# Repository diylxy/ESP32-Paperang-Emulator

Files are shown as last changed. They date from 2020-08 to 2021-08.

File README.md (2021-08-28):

# ESP32 Paperang Emulator

#### 用ESP32 DIY 热敏打印机，模拟Paperang/喵喵机通信协议，可以通过蓝牙连接手机，接收、打印Paperang APP/喵喵机APP/作业帮APP发送的打印数据

## 提示  2021-8-28
#### 这个版本过于不完善，我也在尝试制作2.0版，但是因为学业原因可能需要*很久*，所以推荐两个优秀的二次开发项目，如果资金充足可以考虑：  
[Mao喵喵机热敏打印机--樱猫](https://www.oshwhub.com/SakuraNeko/mao-re-min-da-yin-ji)  
[喵喵机-热敏打印机-改--freedom789](https://www.oshwhub.com/freedom789/print-fpc1)  
因为我比较菜，又要考虑兼容性问题，所以就没有画fpc，这个项目就当是模板吧。这里给各位二次开发者一些建议：  
电池最好更换为2节串联，不要用原版升压芯片，或者电池加超级电容，不然带不动；  
电机驱动可以考虑a4988驱动芯片，不要采用恒压驱动的方式，那样的话电机会非常热；  
原版电路mos管驱动可能有问题，但是能用，这个保护电路不可以省略，不然上电esp32某些引脚默认会上拉或下拉，stb就会激活，烧出一条黑线；  
esp32不需要wrover，根据我的计算60k缓冲区足够打印1m长，把ps_malloc改成malloc就行。  
欢迎大家二次开发并开源，只要注明一下原作者就可以。  
下面是正文  

---
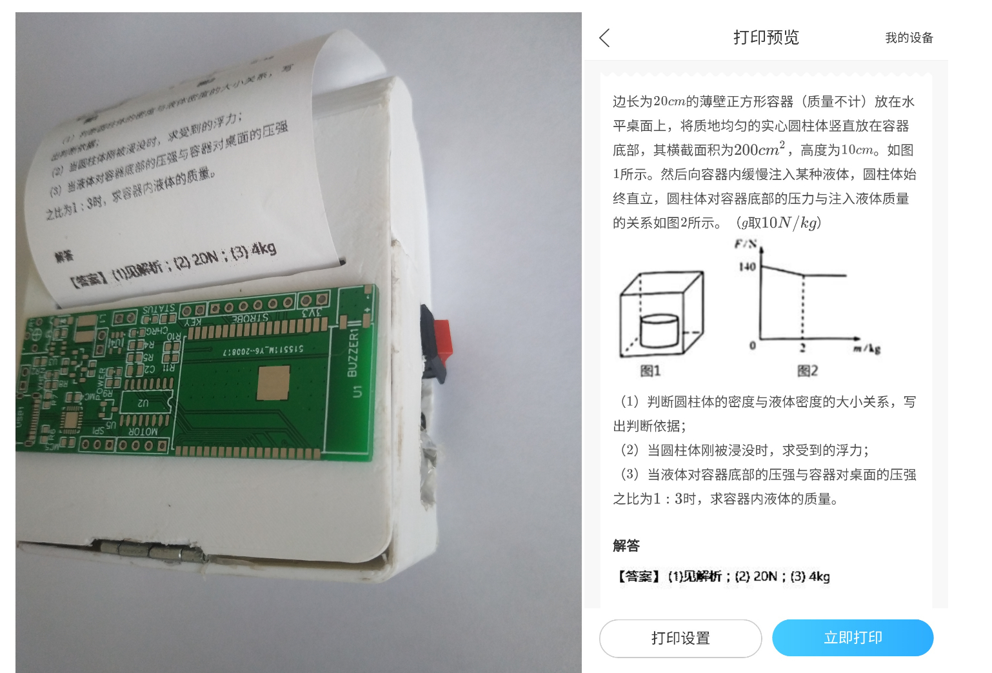
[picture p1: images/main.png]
封面


[Bilibili视频链接](https://www.bilibili.com/video/BV1v54y127xZ )

-----

** 3D模型可能不适合你的打印头,如果打印头尺寸与3D模型相差太大建议重新设计3D模型 **

## 注意事项/调试过程

** 注意：以下内容必须认真阅读，否则可能会出现各种问题，甚至烧坏打印头 **

PCB上的SDA接打印头的SI

已经确认STB5 STB6不能作为输出引脚，ADC和KEY没用到，可以按照视频说明接到那两个引脚上

如果下载程序时不能自动复位可以在ESP32的EN脚对地并联一个20uf以上的电容

如果觉的好别忘了Star :)

### 焊接

焊接时按照元器件从小到大顺序焊接，焊接完成后先检查是否有短路、虚焊、漏焊元件等情况（可以不焊接CP2104和自动复位电路，PCB后面预留有烧录程序用的测试点）

PCB焊接完成后不要立刻焊接打印头测试，先连接电池和开关，将电位器指针调至中间，闭合开关，用万用表直流50V或20V档位测量 VH+ 与 GND 之间的电压，并**缓慢调节**电位器，逆时针旋转升压，顺时针旋转降压。直到输出电压略小于打印头加热元件额定电压，然后焊接打印头。VH+ 可调节的范围：VBAT - 28V，最好不要将电位器调到两端。

我使用的打印头的额定电压为7.2V，型号为三星SMP640, 可作参考

------

将libraries文件夹与esp32开发板安装目录下的libraries文件夹合并，这个文件夹的位置：

Windows，一般在

`C:\Users\Admin\AppData\Local\Arduino15\packages\esp32\hardware\esp32\1.0.4\libraries`

Linux，一般在

`~/.arduino15/packages/esp32/hardware/esp32/1.0.4/libraries`

修改了官方库的缓冲区大小
-----

### 编译/连接/上传

开发板选择ESP32_Wrover_Module，认真核对Printer.ino开头部分的的配置是否符合打印头，然后上传。

上传完成后，如果听到蜂鸣器响1短声，说明启动正常，且 ESP32 的 PSRAM 工作正常。

### 打印测试

在APP中连接打印机，打印**一行**文字，如果打印过程中打印机中途**停止转动**、打印**速度过慢**、文字**颜色过深**或像素点形状**不规则**，请立刻（2秒内）断开开关检查**程序**配置、**电路**连接、打印纸上的**图案**和**串口**输出信息中是否有“ERROR”字样（有就说明有丢包现象），这些信息有助于排错。因为ESP32复位后需要一段时间自检，然后配置IO口。如果开关断开不及时很容易烧坏打印头

默认打印头步进电机转**4**步，打印机走纸**一像素**的距离，如果发现打印的文字长度**过长**或**过扁**，请修改startPrint函数中的goFront1()函数出现位置和次数，这个函数的作用是使打印头步进电机走1步

如果打印正常，就可以把它固定进3D打印的盒子里了

最后，祝大家一次成功（上面说的错误很容易修复，基本都是丢包或配置不当造成的），没有信心可以准备两个型号相同的打印头，用其中一个测试好后换另外一个打印头装盒，这样可以保证打印机做好后打印效果最好。

有什么解决不了的问题或 代码/PCB 的bug请发Issue或PR。建议直接私信作者Bilibili @小李电子实验室  UID:213123506，开学后每三周检查一次私信和评论

-----
## 文件列表：
|文件夹名|描述|
|--|--|
|3D-Model|3D模型|
|images|一些图片|
|libraries|库文件|
|PCB|PCB工程文件和GERBER文件|
|Program|Arduino 程序文件|
|Python|（仅作备份）Python程序|
-----

# 打印头资料

## 一些已找到资料的打印头，到资料来源处直接搜索型号就行

|打印头型号|资料来源|
|:-:|:-:|
|JX-700-48R|百度文库|
|JX-700-02|百度文库|
|SMP640|这个repo的images目录,只有引脚定义|

目前就找到这些比较常见的，淘宝上综合排的靠前，价格<20元的。实在不行到官网上看看没准也可以找到，欢迎提交PR补充

第一脚可以参照电机位置，写着类似A+ A- B+ B- 或AP AM BP BM AN BN之类的引脚一般在电机一侧

-----

这个3D模型可以装下长小于68mm的打印头机芯，和PCB的长相同，小一点没关系。打印头机芯高不能超过30mm，否则请重新设计外壳3D模型，不是特别难，我用的工具是Tkinkercad，直接搜就行

## 在找资料过程中的一些发现

中崎AB-58KII、芯烨XP-58IIIA、精芯JX-700-48R引脚数相同，排线外观相似（前两个的排线一模一样，连分叉的位置都一样，第三个的排线上也就多了两条引出空脚的铜箔，前两个是悬空）

大多数打印头的加热电压(VH)为7.2V，峰值为8.5V

我搜到的所有<20元的57mm热敏打印头都是SPI接口，一个数据锁存控制引脚和六个Strobe引脚（用于选通部分打印头），分辨率每行384点

# 物料清单

|名称|数量|备注|
|:-:|:-:|:-:|
|热敏打印头(机芯)|1|先找资料后购买|
|ESP32-Wrover|1|是Wrover系列就行，否则焊不上去|
|Type-C接口|1||
|贴片蜂鸣器 封装：5020|1|可选|
|TC1508S芯片|1||
|SX1308芯片|3|防止调过头，多买两个|
|CP2104 QFN24|1|可选，USB转串口芯片，不会拖焊QFN可以买焊锡膏吹焊，PCB如果没订钢网不建议买瓶装的，太干不好用。拖焊技巧：一大坨助焊剂，干它就完了|
|3362电位器 100K|1||
|AON6512 N-MOS QFN-8|1|或者一坨锡连接DS极，这里的mos感觉没什么用，可能是电路有问题，拆了直接连起来不影响使用|
|XC6206P332 (或者662k) SOT23-3|1|3.3V LDO|
|SS8050 SOT23-3|10|可能用不了这么多，但是一般都是几十个一起卖。SS8050>S8050，可以直接代换|
|10k电阻 0603|一组(不是64)|一般至少卖50个|
|200欧姆电阻/200R 0603|一组|同上|
|LTC4054 SOT23-5|1|锂电池充电管理芯片|
|LED 0603|>5|颜色随意，多买几个防止焊坏|
|1N5822|1||
|2.2K电阻 0603|>2||
|1UF电容 0603|一组||
|0805 电容|1|绿波用，大亿点没关系，耐压>=10V|
|锂电池+保护板|1|可以是18650，刚好放得下。最好用动力电池|
|船形开关 10x15mm |1|用别的开关也行。我的这个模型开关孔和USB孔要自己看好PCB安装位置切，或者改模型。一是因为每个人的电池和打印头大小可能不同，开孔位置不固定，二是3D打印机直接打印容易凹陷，我又不想加支撑|
|...|...|应该没什么了，LED限流电阻都用200欧没问题，0603电容全部用1uf|

## 参考资料链接

[喵喵机折腾记-ihcblog](https://www.ihcblog.com/miaomiaoji/ )

[hansel163-paperang_printer](https://github.com/hansel163/paperang_printer )

先整理这么多吧

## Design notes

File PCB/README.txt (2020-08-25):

Gerber_PCB.zip为GERBER 文件
Project_Thermal_Printer.zip 为立创EDA工程文件，包括原理图和PCB，直接导入就可以
DLC最小线距5mil,过孔外径有几个0.45mm的，比嘉立创规定的0.61mm小，但是打样回来能用
PCB 有一定修改，加宽了一些导线保证能过大电流，把部分过孔外径修改为0.61mm

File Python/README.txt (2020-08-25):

这是Python版的上位机程序，因为WiFi部分的代码已被注释，只保留了蓝牙连接的代码，所以不能用这个程序连接打印机，放在这里做个备份，现在可以使用Paperang/喵喵机手机应用程序连接打印
程序使用到的模块有：
tkinter pygame qrcode pillow requests
直接pip安装就行

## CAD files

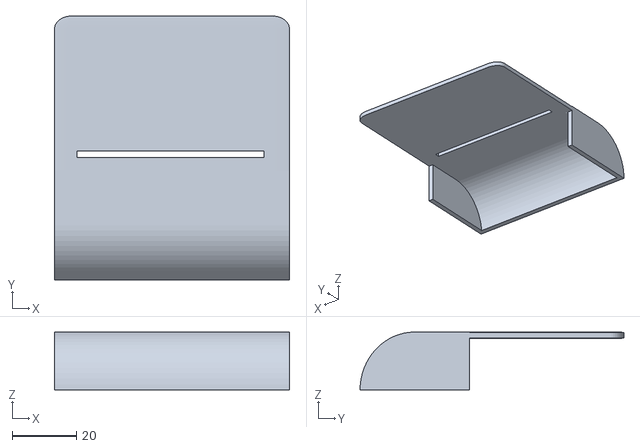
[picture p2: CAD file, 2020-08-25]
3D-Model/Top.stl
73.0 x 82.0 x 18.0

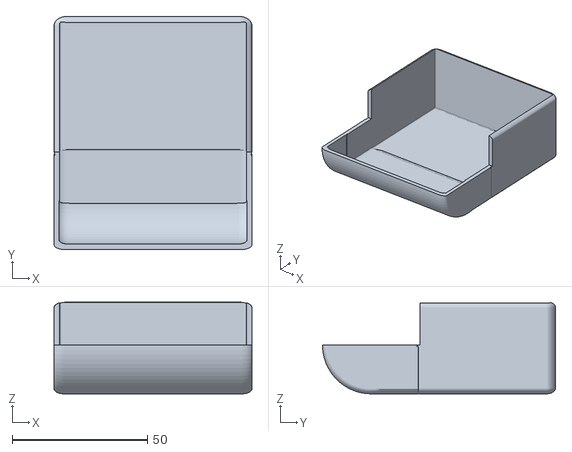
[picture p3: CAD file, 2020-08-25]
3D-Model/Bottom.stl
73.0 x 86.0 x 33.9

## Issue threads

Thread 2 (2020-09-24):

还是经常丢包，有什么解决办法么？

cjx1995, 2020-09-24:
Brownout detector was triggered

3秒内输入要测试的STB序号开始打印测试页（1-6）:
ERROR
ERROR
[INFO]正在打印...
[INFO]共384行
[INFO]打印完成
ERROR
ERROR
[INFO]正在打印...
[INFO]共535行
[INFO]打印完成

1452206376, 2020-09-30:
可能是天线被遮挡或者根本没装天线，esp32 wrover i默认使用ipex天线，可以重焊天线旁边的电阻改pcb天线。刚测试打印1000行以上的截图没有error。
下次issue在上一个的下面直接发就行，不必重开一个

Closed 2021-02-20.

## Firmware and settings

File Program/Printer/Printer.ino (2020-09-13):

/*#include <WiFi.h>
  #include <WiFiClient.h>
  #include <WebServer.h>
  #include <ESPmDNS.h>
*/
#include <SPI.h>
#include "esp_task_wdt.h"

/*
  const char* host = "esp32-Printer";
  const char* ssid = "ssid";
  const char* password = "password";
  const char* softAP_ssid = "Printer";
  const char* softAP_password = "myprinter";
*/
#define PIN_MOTOR_AP 23
#define PIN_MOTOR_AM 22
#define PIN_MOTOR_BP 21
#define PIN_MOTOR_BM 19

#define PIN_LAT 18
#define PIN_SCK 5
#define PIN_SDA 4

#define PIN_STB1 26
#define PIN_STB2 25
#define PIN_STB3 33
#define PIN_STB4 32
#define PIN_STB5 14
#define PIN_STB6 27

#define PIN_BUZZER 15
#define BUZZER_FREQ 2000
#define startBeep() ledcWrite(0, 127)
#define stopBeep() ledcWrite(0,0)

#define PIN_STATUS 13
#define PIN_VHEN 2

#define MOTOR_STEP_PER_LINE 3
#define PRINT_TIME 1700
#define PRINT_TIME_ 200
#define MOTOR_TIME 4000
float addTime[6] = {0};
float tmpAddTime = 0;
//根据打印头打印效果修改
#define kAddTime 0.001      //点数-增加时间系数, 见sendData函数
#define STB1_ADDTIME 100    //STB1额外打印时间,下面类似, 单位: 微秒
#define STB2_ADDTIME 100      //根据打印头实际情况修改
#define STB3_ADDTIME -100
#define STB4_ADDTIME 0
#define STB5_ADDTIME 700
#define STB6_ADDTIME 800
extern uint8_t heat_density;
//WebServer server(80);

// char* serverIndex = "<form method='POST' action='/upload' enctype='multipart/form-data'><input type='file' name='upload'><input type='submit' value='Upload'></form>";
////////////////////////////////////////////////////////////////////////////////////////////////////////////////////////////////
//步进电机驱动部分
uint8_t motorTable[8][4] =
{
  {1, 0, 0, 0},
  {1, 0, 1, 0},
  {0, 0, 1, 0},
  {0, 1, 1, 0},
  {0, 1, 0, 0},
  {0, 1, 0, 1},
  {0, 0, 0, 1},
  {1, 0, 0, 1}
};
uint8_t motorPos = 0;

void goFront(uint32_t steps, uint16_t wait)
{
  ++steps;
  while (--steps)
  {
    digitalWrite(PIN_MOTOR_AP, motorTable[motorPos][0]);
    digitalWrite(PIN_MOTOR_AM, motorTable[motorPos][1]);
    digitalWrite(PIN_MOTOR_BP, motorTable[motorPos][2]);
    digitalWrite(PIN_MOTOR_BM, motorTable[motorPos][3]);
    ++motorPos;
    if (motorPos == 8)
    {
      motorPos = 0;
    }
    delayMicroseconds(wait);
  }
  digitalWrite(PIN_MOTOR_AP, 0);
  digitalWrite(PIN_MOTOR_AM, 0);
  digitalWrite(PIN_MOTOR_BP, 0);
  digitalWrite(PIN_MOTOR_BM, 0);
}
void goFront1()
{
  digitalWrite(PIN_MOTOR_AP, motorTable[motorPos][0]);
  digitalWrite(PIN_MOTOR_AM, motorTable[motorPos][1]);
  digitalWrite(PIN_MOTOR_BP, motorTable[motorPos][2]);
  digitalWrite(PIN_MOTOR_BM, motorTable[motorPos][3]);
  ++motorPos;
  if (motorPos == 8)
  {
    motorPos = 0;
  }
}

//////////////////////////////////////////////////////////////////////////////////////////////////////////////////////////////////////
//打印头驱动部分
uint8_t *printData;
uint32_t printDataCount = 0;
SPIClass printerSPI = SPIClass(HSPI);
SPISettings printerSPISettings = SPISettings(1000000, SPI_MSBFIRST, SPI_MODE0);

void clearAddTime()
{
  addTime[0] = addTime[1] = addTime[2] = addTime[3] = addTime[4] = addTime[5] = 0;
}
void sendData(uint8_t *dataPointer)
{
  for (uint8_t i = 0; i < 6; ++i)
  {
    for (uint8_t j = 0; j < 8; ++j)
    {
      addTime[i] += dataPointer[i * 8 + j];
    }
    tmpAddTime = addTime[i] * addTime[i];
    addTime[i] = kAddTime * tmpAddTime;
  }
  printerSPI.beginTransaction(printerSPISettings);
  printerSPI.transfer(dataPointer, 48);
  printerSPI.endTransaction();

  digitalWrite(PIN_LAT, 0);
  delayMicroseconds(1);
  digitalWrite(PIN_LAT, 1);
}

void clearData(void)
{
  printerSPI.beginTransaction(printerSPISettings);
  for (uint8_t i = 0; i < 48; ++i) {
    printerSPI.transfer(0);
  }
  printerSPI.endTransaction();
  clearAddTime();
  digitalWrite(PIN_LAT, 0);
  delayMicroseconds(1);
  digitalWrite(PIN_LAT, 1);
}

void startPrint()
{
  static unsigned char motor_add = 0;
  startBeep();
  delay(200);
  stopBeep();

  Serial.println("[INFO]正在打印...");
  Serial.printf("[INFO]共%u行\n", printDataCount / 48);
  digitalWrite(PIN_VHEN, 1);
  for (uint32_t pointer = 0; pointer < printDataCount; pointer += 48)
  {

    motor_add ++;
    if (motor_add != 40)
    {
      delayMicroseconds((PRINT_TIME) * ((double)heat_density / 100));
      goFront1();
    }
    else
    {
      motor_add = 0;
    }
    clearAddTime();
    sendData(printData + pointer);
    digitalWrite(PIN_STB1, 1);
    delayMicroseconds((PRINT_TIME + addTime[0] + STB1_ADDTIME) * ((double)heat_density / 100));
    digitalWrite(PIN_STB1, 0);
    delayMicroseconds(PRINT_TIME_);

    digitalWrite(PIN_STB2, 1);
    delayMicroseconds((PRINT_TIME + addTime[1] + STB2_ADDTIME) * ((double)heat_density / 100));
    digitalWrite(PIN_STB2, 0);
    delayMicroseconds(PRINT_TIME_);
    goFront1();

    digitalWrite(PIN_STB3, 1);
    delayMicroseconds((PRINT_TIME + addTime[2] + STB3_ADDTIME) * ((double)heat_density / 100));
    digitalWrite(PIN_STB3, 0);
    delayMicroseconds(PRINT_TIME_);

    digitalWrite(PIN_STB4, 1);
    delayMicroseconds((PRINT_TIME + addTime[3] + STB4_ADDTIME) * ((double)heat_density / 100));
    digitalWrite(PIN_STB4, 0);
    delayMicroseconds(PRINT_TIME_);
    goFront1();

    digitalWrite(PIN_STB5, 1);
    delayMicroseconds((PRINT_TIME + addTime[4] + STB5_ADDTIME) * ((double)heat_density / 100));
    digitalWrite(PIN_STB5, 0);
    delayMicroseconds(PRINT_TIME_);

    digitalWrite(PIN_STB6, 1);
    delayMicroseconds((PRINT_TIME + addTime[5] + STB6_ADDTIME) * ((double)heat_density / 100));
    digitalWrite(PIN_STB6, 0);
    delayMicroseconds(PRINT_TIME_);
    goFront1();
  }

  digitalWrite(PIN_MOTOR_AP, 0);
  digitalWrite(PIN_MOTOR_AM, 0);
  digitalWrite(PIN_MOTOR_BP, 0);
  digitalWrite(PIN_MOTOR_BM, 0);
  clearAddTime();
  clearSTB();
  clearData();
  printDataCount = 0;
  Serial.println("[INFO]打印完成");
  digitalWrite(PIN_VHEN, 0);
  startBeep();
  delay(100);
  stopBeep();
  delay(50);
  startBeep();
  delay(100);
  stopBeep();
}

void startPrint(uint8_t stb)
{
  static unsigned char motor_add = 0;
  startBeep();
  delay(700);
  stopBeep();

  Serial.printf("[INFO]正在打印STB%c\n", stb + 0x31);
  Serial.printf("[INFO]共%u行\n", printDataCount / 48);
  digitalWrite(PIN_VHEN, 1);
  for (uint32_t pointer = 0; pointer < printDataCount; pointer += 48)
  {

    motor_add ++;
    if (motor_add != 40)
    {
      delayMicroseconds((PRINT_TIME) * ((double)heat_density / 100));
      goFront1();
    }
    else
    {
      motor_add = 0;
    }
    clearAddTime();
    sendData(printData + pointer);
    switch (stb)
    {
      case 0:
        digitalWrite(PIN_STB1, 1);
        delayMicroseconds((PRINT_TIME + addTime[0] + STB1_ADDTIME) * ((double)heat_density / 100));
        digitalWrite(PIN_STB1, 0);
        delayMicroseconds(PRINT_TIME_);
        break;
      case 1:
        digitalWrite(PIN_STB2, 1);
        delayMicroseconds((PRINT_TIME + addTime[1] + STB2_ADDTIME) * ((double)heat_density / 100));
        digitalWrite(PIN_STB2, 0);
        delayMicroseconds(PRINT_TIME_);
        break;
      case 2:
        digitalWrite(PIN_STB3, 1);
        delayMicroseconds((PRINT_TIME + addTime[2] + STB3_ADDTIME) * ((double)heat_density / 100));
        digitalWrite(PIN_STB3, 0);
        delayMicroseconds(PRINT_TIME_);
        break;
      case 3:
        digitalWrite(PIN_STB4, 1);
        delayMicroseconds((PRINT_TIME + addTime[3] + STB4_ADDTIME) * ((double)heat_density / 100));
        digitalWrite(PIN_STB4, 0);
        delayMicroseconds(PRINT_TIME_);
        break;
      case 4:
        digitalWrite(PIN_STB5, 1);
        delayMicroseconds((PRINT_TIME + addTime[4] + STB5_ADDTIME) * ((double)heat_density / 100));
        digitalWrite(PIN_STB5, 0);
        delayMicroseconds(PRINT_TIME_);
        break;
      case 5:
        digitalWrite(PIN_STB6, 1);
        delayMicroseconds((PRINT_TIME + addTime[5] + STB6_ADDTIME) * ((double)heat_density / 100));
        digitalWrite(PIN_STB6, 0);
        delayMicroseconds(PRINT_TIME_);
        break;
    }
    goFront(3, 3000);
  }

  digitalWrite(PIN_MOTOR_AP, 0);
  digitalWrite(PIN_MOTOR_AM, 0);
  digitalWrite(PIN_MOTOR_BP, 0);
  digitalWrite(PIN_MOTOR_BM, 0);
  clearAddTime();
  clearSTB();
  clearData();
  digitalWrite(PIN_VHEN, 0);
  startBeep();
  delay(100);
  stopBeep();
  delay(50);
  startBeep();
  delay(100);
  stopBeep();
}

void setupPins() {
  pinMode(PIN_MOTOR_AP, OUTPUT);
  pinMode(PIN_MOTOR_AM, OUTPUT);
  pinMode(PIN_MOTOR_BP, OUTPUT);
  pinMode(PIN_MOTOR_BM, OUTPUT);
  digitalWrite(PIN_MOTOR_AP, 0);
  digitalWrite(PIN_MOTOR_AM, 0);
  digitalWrite(PIN_MOTOR_BP, 0);
  digitalWrite(PIN_MOTOR_BM, 0);

  pinMode(PIN_LAT, OUTPUT);
  pinMode(PIN_SCK, OUTPUT);
  pinMode(PIN_SDA, OUTPUT);

  pinMode(PIN_STB1, OUTPUT);
  pinMode(PIN_STB2, OUTPUT);
  pinMode(PIN_STB3, OUTPUT);
  pinMode(PIN_STB4, OUTPUT);
  pinMode(PIN_STB5, OUTPUT);
  pinMode(PIN_STB6, OUTPUT);
  digitalWrite(PIN_STB1, 0);
  digitalWrite(PIN_STB2, 0);
  digitalWrite(PIN_STB3, 0);
  digitalWrite(PIN_STB4, 0);
  digitalWrite(PIN_STB5, 0);
  digitalWrite(PIN_STB6, 0);

  pinMode(PIN_STATUS, OUTPUT);
  digitalWrite(PIN_STATUS, 0);
  pinMode(PIN_VHEN, OUTPUT);
  digitalWrite(PIN_VHEN, 0);
  ledcSetup(0, 1000, 8);
  ledcAttachPin(PIN_BUZZER, 0);
  ledcWrite(0, 0);

  printerSPI.begin(PIN_SCK, -1, PIN_SDA, -1);
  printerSPI.setFrequency(2000000);
  clearSTB();
  clearData();

}

void clearSTB()
{
  digitalWrite(PIN_STB1, 0);
  digitalWrite(PIN_STB2, 0);
  digitalWrite(PIN_STB3, 0);
  digitalWrite(PIN_STB4, 0);
  digitalWrite(PIN_STB5, 0);
  digitalWrite(PIN_STB6, 0);

}

void setup(void) {
  Serial.begin(115200);
  setupPins();
  //下面是配置wifi，为了防止干扰蓝牙打印，关闭wifi功能
  /*
    WiFi.mode(WIFI_AP_STA);
    WiFi.begin(ssid, password);
    if (WiFi.waitForConnectResult() != WL_CONNECTED) {
    Serial.println("softAP Mode");
    WiFi.softAP(softAP_ssid, softAP_password);
    }

    server.on("/", HTTP_GET, []() {
    server.sendHeader("Connection", "close");
    server.send(200, "text/html", serverIndex);
    });
    server.on("/upload", HTTP_POST, []() {
    server.sendHeader("Connection", "close");
    server.send(200, "text/plain", "OK");
    startPrint();
    }, []() {
    HTTPUpload& upload = server.upload();
    if (upload.status == UPLOAD_FILE_START) {
      Serial.printf("[INFO]开始上传\n文件名: %s\n", upload.filename.c_str());
      printDataCount = 0;
      digitalWrite(PIN_STATUS, 1);
      startBeep();
      delay(100);
      stopBeep();
    } else if (upload.status == UPLOAD_FILE_WRITE) {
      memcpy(printData + printDataCount, upload.buf, upload.currentSize);
      printDataCount += upload.currentSize;
    } else if (upload.status == UPLOAD_FILE_END) {
      Serial.printf("[INFO]上传完成: 收到：%u||发送：%u\n", printDataCount, upload.totalSize);
      digitalWrite(PIN_STATUS, 0);
    }
    });

    server.on("/lineFeed/{}", []() {
    uint32_t lines = atoi(server.pathArg(0).c_str()) * MOTOR_STEP_PER_LINE;
    goFront(lines, MOTOR_TIME);
    server.send(200, "OK");
    });
  */
  //server.begin();

  printData = (uint8_t*)ps_malloc(3 * 1024 * 1024);
  if (!printData) {
    startBeep();
    Serial.println("[ERROR]PSRAM Malloc 失败!\n    请确认esp32模组型号为wrover且须在arduino->开发板中选择ESP32 Wrover Module");
    delay(500);
    stopBeep();
    while (1);
  }
  startBeep();
  delay(50);
  stopBeep();
  //paperang_core0();
  paperang_app();
}

//打印头测试
void testPage(uint8_t stb)
{
  Serial.println("开始打印 颜色深度-同时打印点数 测试页\n可根据此页调整加热时间常数");
  uint8_t printchr[8] = {0};
  uint8_t i, j, k;
  uint8_t dots, dotsnow;
  printDataCount = 0;
  for (uint32_t cleardata = 0; cleardata < 102400; ++cleardata)
  {
    printData[cleardata] = 0;
  }
  for (uint8_t dots = 0; dots < 64; dots += 4)
  {
    for (k = 0; k < 5; ++k)
    {
      dotsnow = 0;
      for (i = 0; i < 8; ++i)
      {
        printchr[i] = 0;
      }

      for (i = 0; i < 8; ++i)
      {
        for (j = 0; j < 8; ++j)
        {
          if (dotsnow == dots)
          {
            break;
          }
          dotsnow++;
          printchr[i] |= (0x80 >> j);
        }
      }
      memcpy(printData + printDataCount + 8, printchr, 8);
      memcpy(printData + printDataCount + 16, printchr, 8);
      memcpy(printData + printDataCount + 24, printchr, 8);
      memcpy(printData + printDataCount + 32, printchr, 8);
      memcpy(printData + printDataCount + 40, printchr, 8);
      memcpy(printData + printDataCount + 48, printchr, 8);
      printDataCount += 48;
    }
    printDataCount += 48 * 3;
  }
  startBeep();
  delay(100);
  stopBeep();
  delay(50);
  startBeep();
  delay(200);
  stopBeep();
  delay(50);
  startBeep();
  delay(100);
  stopBeep();
  delay(50);
  startPrint(stb);
  goFront(40 * 4, MOTOR_TIME);
  printDataCount = 0;
}

void testSTB()
{
  Serial.println("开始打印打印头选通引脚(Strobe)测试页\n顺序:开头  1  2  3  4  5  6");
  for (uint32_t cleardata = 0; cleardata < 48*5; ++cleardata)
  {
    printData[cleardata] = 0xff;
  }
  printDataCount = 48 * 5;
  startPrint(0);
  startPrint(1);
  startPrint(2);
  startPrint(3);
  startPrint(4);
  startPrint(5);
  startBeep();
  delay(200);
  stopBeep();
  delay(50);
  startBeep();
  delay(200);
  stopBeep();
  delay(50);
  startBeep();
  delay(100);
  stopBeep();
  delay(50);
  goFront(40 * 4, MOTOR_TIME);
  printDataCount = 0;
}

void loop(void) {
  //server.handleClient();
  //  delay(1);
}

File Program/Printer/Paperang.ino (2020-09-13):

#include <BluetoothSerial.h>
#include "Arduino_CRC32.h"
#include "esp_bt.h"
#include "esp_bt_main.h"
#include "esp_gap_bt_api.h"
#include "esp_bt_device.h"
#include "esp_spp_api.h"
#include "esp_task_wdt.h"
#if !defined(CONFIG_BT_ENABLED) || !defined(CONFIG_BLUEDROID_ENABLED)
#error Bluetooth is not enabled! Please run `make menuconfig` to and enable it
#endif

#define MOTOR_TIME 3000

extern uint8_t *printData;
extern uint32_t printDataCount;

#define START_BYTE 0x02
#define END_BYTE 0x03
#define PRINTER_SN "P1001705253855"
#define PRINTER_NAME "P1"
uint8_t PRINTER_BATTERY = 90;
#define COUNTRY_NAME "CN"
char *CMD_42_DATA PROGMEM = "BK3432";
uint8_t CMD_7F_DATA[] PROGMEM = {0x76, 0x33, 0x2e, 0x33, 0x38, 0x2e, 0x31, 0x39, 0, 0, 0, 0};
uint8_t CMD_81_DATA[] PROGMEM = {0x48, 0x4d, 0x45, 0x32, 0x33, 0x30, 0x5f, 0x50, 0x32, 0, 0, 0, 0, 0, 0, 0};
uint8_t PRINTER_VERSION[] PROGMEM = {0x08, 0x01, 0x01};
uint8_t *CMD_40_DATA PROGMEM = {0x00};
uint32_t power_down_time = 3600;
uint8_t heat_density = 75;

#define PRINT_DATA 0
#define PRINT_DATA_COMPRESS 1
#define FIRMWARE_DATA 2
#define USB_UPDATE_FIRMWARE 3
#define GET_VERSION 4
#define SENT_VERSION 5
#define GET_MODEL 6
#define SENT_MODEL 7
#define GET_BT_MAC 8
#define SENT_BT_MAC 9
#define GET_SN 10
#define SENT_SN 11
#define GET_STATUS 12
#define SENT_STATUS 13
#define GET_VOLTAGE 14
#define SENT_VOLTAGE 15
#define GET_BAT_STATUS 16
#define SENT_BAT_STATUS 17
#define GET_TEMP 18
#define SENT_TEMP 19
#define SET_FACTORY_STATUS 20
#define GET_FACTORY_STATUS 21
#define SENT_FACTORY_STATUS 22
#define SENT_BT_STATUS 23
#define SET_CRC_KEY 24
#define SET_HEAT_DENSITY 25
#define FEED_LINE 26
#define PRINT_TEST_PAGE 27
#define GET_HEAT_DENSITY 28
#define SENT_HEAT_DENSITY 29
#define SET_POWER_DOWN_TIME 30
#define GET_POWER_DOWN_TIME 31
#define SENT_POWER_DOWN_TIME 32
#define FEED_TO_HEAD_LINE 33
#define PRINT_DEFAULT_PARA 34
#define GET_BOARD_VERSION 35
#define SENT_BOARD_VERSION 36
#define GET_HW_INFO 37
#define SENT_HW_INFO 38
#define SET_MAX_GAP_LENGTH 39
#define GET_MAX_GAP_LENGTH 40
#define SENT_MAX_GAP_LENGTH 41
#define GET_PAPER_TYPE 42
#define SENT_PAPER_TYPE 43
#define SET_PAPER_TYPE 44
#define GET_COUNTRY_NAME 45
#define SENT_COUNTRY_NAME 46
#define DISCONNECT_BT 47
#define GET_DEV_NAME 48
#define SENT_DEV_NAME 49
#define CMD_39 57
#define CMD_40 64
#define CMD_41 65
#define CMD_42 66
#define CMD_43 67
#define CMD_7F 127
#define CMD_80 128
#define CMD_81 129
#define CMD_82 130

BluetoothSerial SerialBT;
Arduino_CRC32 crc32;
uint8_t dataPack[512];
uint32_t dataPack_len;
uint32_t crc32_result;
void paperang_send(void)
{
  SerialBT.write(dataPack, dataPack_len);
}

void paperang_send_ack(uint8_t type)
{
  uint8_t ackcrc = 0;
  dataPack[0] = START_BYTE;
  dataPack[1] = type;
  dataPack[2] = 0x00;
  dataPack[3] = 0x01;
  dataPack[4] = 0x00;
  dataPack[5] = 0x00;
  crc32_result = crc32.calc(&ackcrc, 1);
  memcpy(dataPack + 6, (uint8_t *)&crc32_result, 4);
  dataPack[10] = END_BYTE;
  dataPack_len = 11;
  paperang_send();
}

void paperang_send_msg(uint8_t type, const uint8_t* dat, uint16_t len)
{
  dataPack[0] = START_BYTE;
  dataPack[1] = type;
  dataPack[2] = 0x00;
  memcpy(dataPack + 3, (uint8_t *)&len, 2);
  memcpy(dataPack + 5, dat, len);
  dataPack_len = 5 + len;
  crc32_result = crc32.calc(dat, len);
  memcpy(dataPack + dataPack_len, (uint8_t *)&crc32_result, 4);
  dataPack[dataPack_len + 4] = END_BYTE;
  dataPack_len += 5;
  paperang_send();
}

struct {
  uint8_t packType;
  uint8_t packIndex;
  uint16_t dataLen;
} packHeader;
uint8_t gotStartByte = 0;
uint8_t c;
uint16_t readpos = 0;
uint8_t dataPack_read[2048];
//#define PRINT_DATA_CACHE_SIZE 10240
//uint8_t printDataCache[PRINT_DATA_CACHE_SIZE + 1024];
//volatile uint16_t cacheOverflowed = 0;
//volatile uint16_t printDataCacheHead = 0;
//volatile uint16_t printDataCacheFoot = 0;
uint16_t dataPack_read_pos = 0;
//volatile uint8_t cacheLock = 0;
void paperang_process_data()
{
  uint32_t tmp32;
  switch (packHeader.packType)
  {
    case PRINT_DATA:
      /*
        //while (cacheLock);
        //cacheLock = 1;
        memcpy(printDataCache + printDataCacheHead, dataPack_read, packHeader.dataLen);
        printDataCacheHead += packHeader.dataLen;
        if (printDataCacheHead >= PRINT_DATA_CACHE_SIZE)
        {
          printDataCacheHead = 0;
          cacheOverflowed = printDataCacheHead - PRINT_DATA_CACHE_SIZE;
        }
        //cacheLock = 0;*/
      return;
    case SET_CRC_KEY:
      tmp32 = dataPack_read[0] << 24 + dataPack_read[1] << 16 + dataPack_read[2] << 8 + dataPack_read[3];
      crc32.init(tmp32);
      break;
    case GET_VERSION:
      paperang_send_msg(SENT_VERSION, PRINTER_VERSION, 3);
      break;
    case GET_DEV_NAME:
      paperang_send_msg(SENT_DEV_NAME, (uint8_t *)PRINTER_NAME, 2);
      break;
    case GET_SN:
      paperang_send_msg(SENT_SN, (uint8_t *)PRINTER_SN, strlen((char *)PRINTER_SN));
    case GET_POWER_DOWN_TIME:
      paperang_send_msg(SENT_POWER_DOWN_TIME, (uint8_t *)&power_down_time, 2);
      break;
    case GET_BAT_STATUS:
      paperang_send_msg(SENT_BAT_STATUS, &PRINTER_BATTERY, 1);
      break;
    case GET_COUNTRY_NAME:
      paperang_send_msg(SENT_COUNTRY_NAME, (uint8_t *)COUNTRY_NAME, 2);
      break;
    case CMD_42:
      paperang_send_msg(CMD_43, (uint8_t *)CMD_42_DATA, strlen(CMD_42_DATA));
      break;
    case CMD_7F:
      paperang_send_msg(CMD_80, CMD_7F_DATA, 12);
      break;
    case CMD_81:
      paperang_send_msg(CMD_82, CMD_81_DATA, 16);
      break;
    case CMD_40:
      paperang_send_msg(CMD_41, CMD_40_DATA, 1);
      break;
    case SET_POWER_DOWN_TIME:
      power_down_time = dataPack_read[0] << 8 + dataPack_read[1];
      break;
    case SET_HEAT_DENSITY:
      heat_density = dataPack_read[0];
      break;
    case GET_HEAT_DENSITY:
      paperang_send_msg(SENT_HEAT_DENSITY, &heat_density, 1);
      break;
    case FEED_LINE:
      if (printDataCount / 48 != 0) {
        startPrint();
        goFront(200, MOTOR_TIME);
      }
      printDataCount = 0;
      break;
    default:
      break;
  }
  paperang_send_ack(packHeader.packType);
}
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
